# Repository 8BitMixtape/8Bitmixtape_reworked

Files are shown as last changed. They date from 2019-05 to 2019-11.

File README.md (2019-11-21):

# MixtapeNEO reworked
It's not really new... but finally fully working wiht KiCAD and svg2Shenzhen.
Reworked the "classic" 8Bit Mixtape NEO, now with new design, working amplifier 8002 and integrated speaker. Repsoitionend the battery holders, added holes for the speaker and improved the footprints hand-soldering.

## Fully redesigned version

Clone / fork this repo and make your own design!!

### Digilog Version

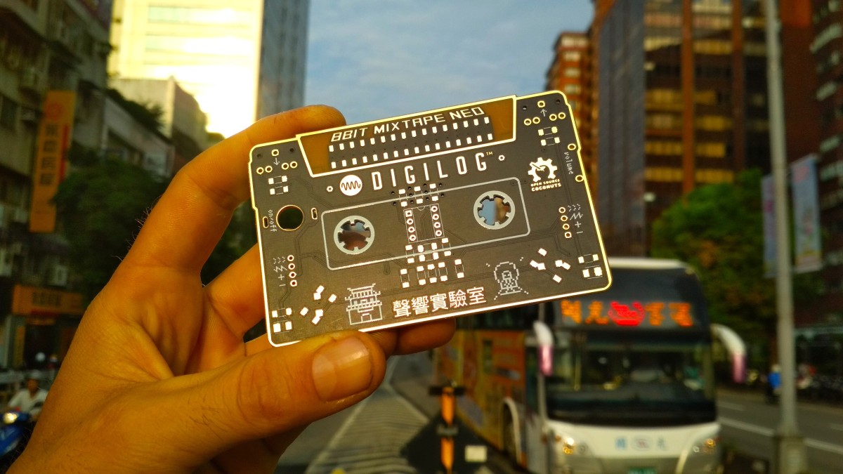
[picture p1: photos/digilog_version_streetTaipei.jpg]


### Pixelache Version

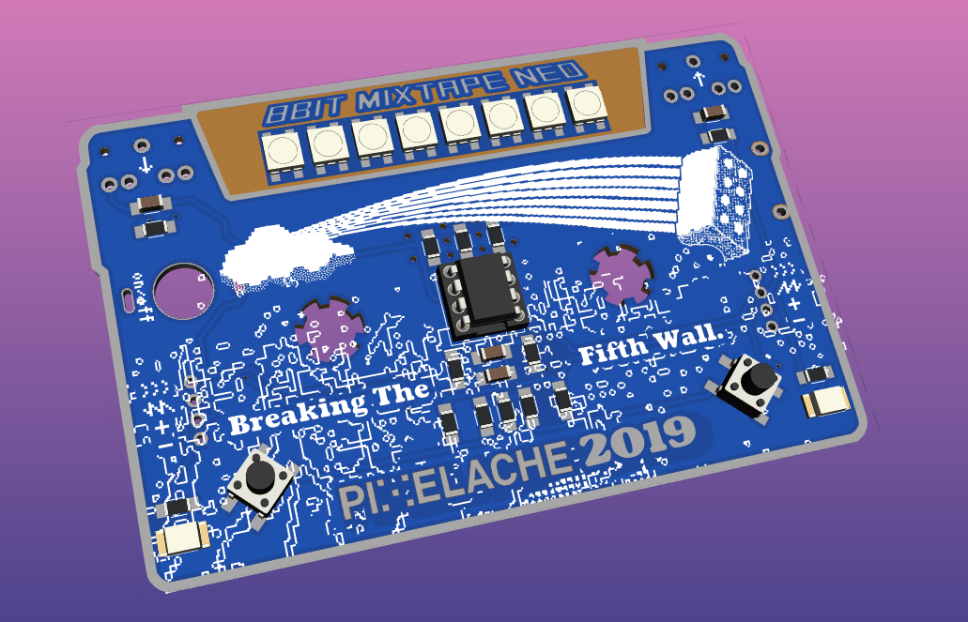
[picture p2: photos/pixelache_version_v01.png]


A limited edition of the Pixelache 2019 Mixtape kits are available from Steve Maher, get in contact with hom on fbook: https://www.facebook.com/steve.maher.39

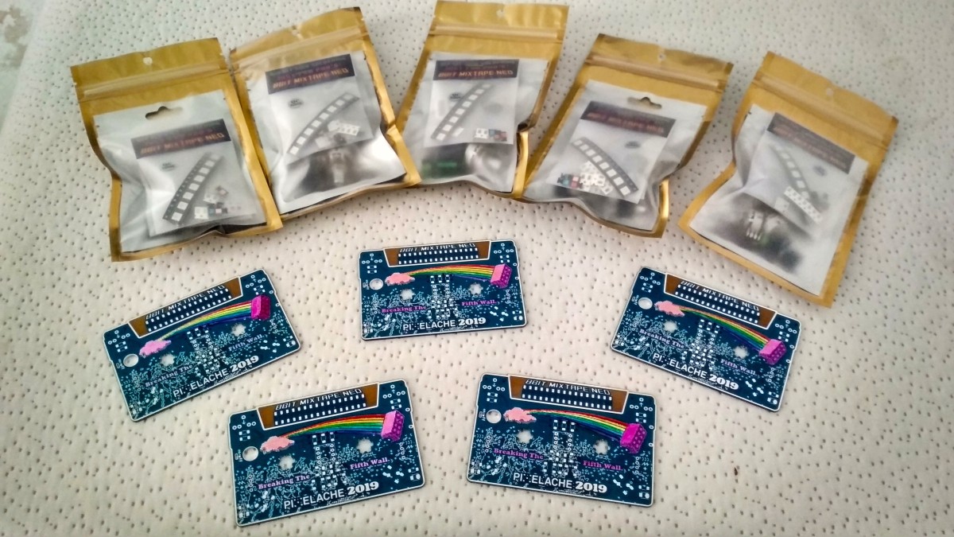
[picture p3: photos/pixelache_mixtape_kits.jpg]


### Make your own Designs!

Modify it in other shapes, such as Eurorack? Make a really really small one? Simplfy it as a little sound toy?

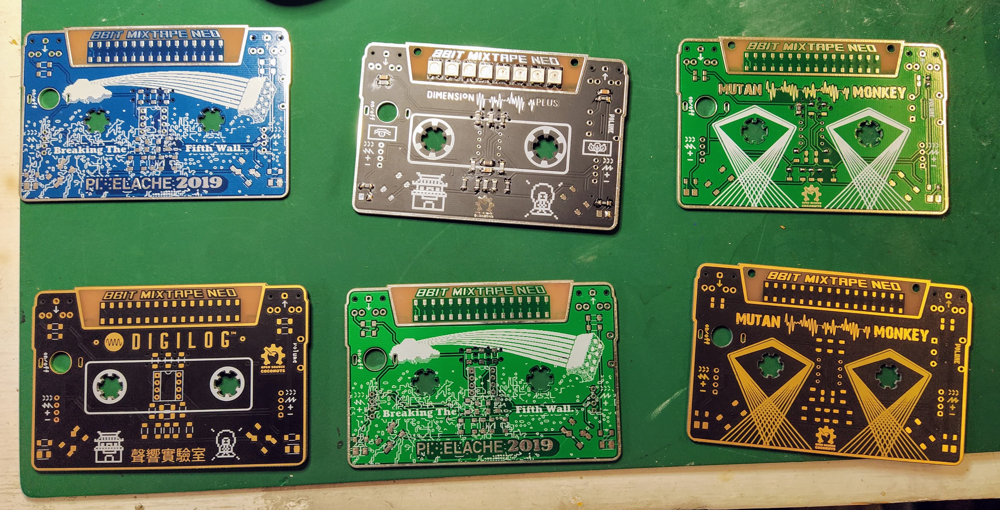
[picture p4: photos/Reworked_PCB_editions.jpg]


### Print your own 3d-case

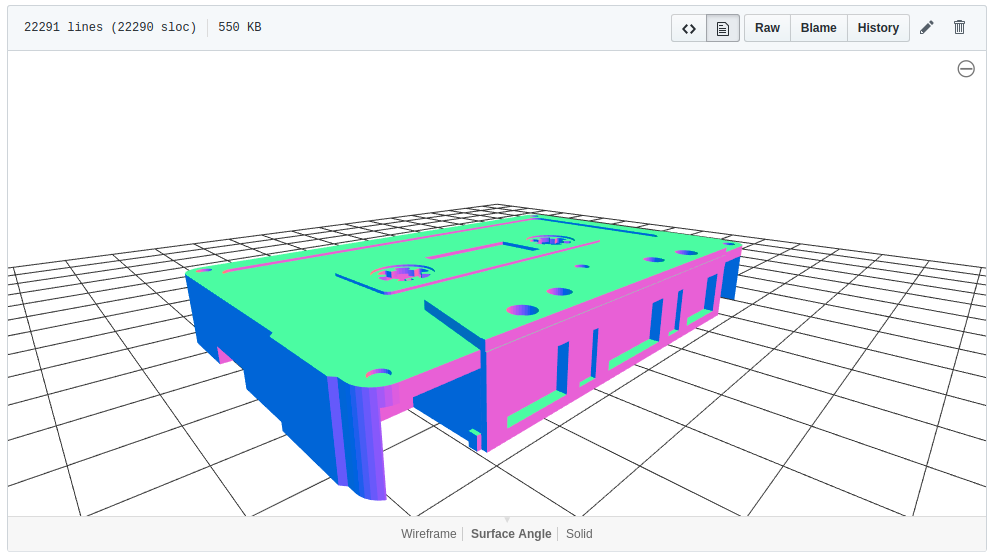
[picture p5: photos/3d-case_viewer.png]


https://github.com/8BitMixtape/8Bitmixtape_reworked/blob/master/3d-case/MixTape_Case_VerMayl19_11.stl

## Soldering Instruction

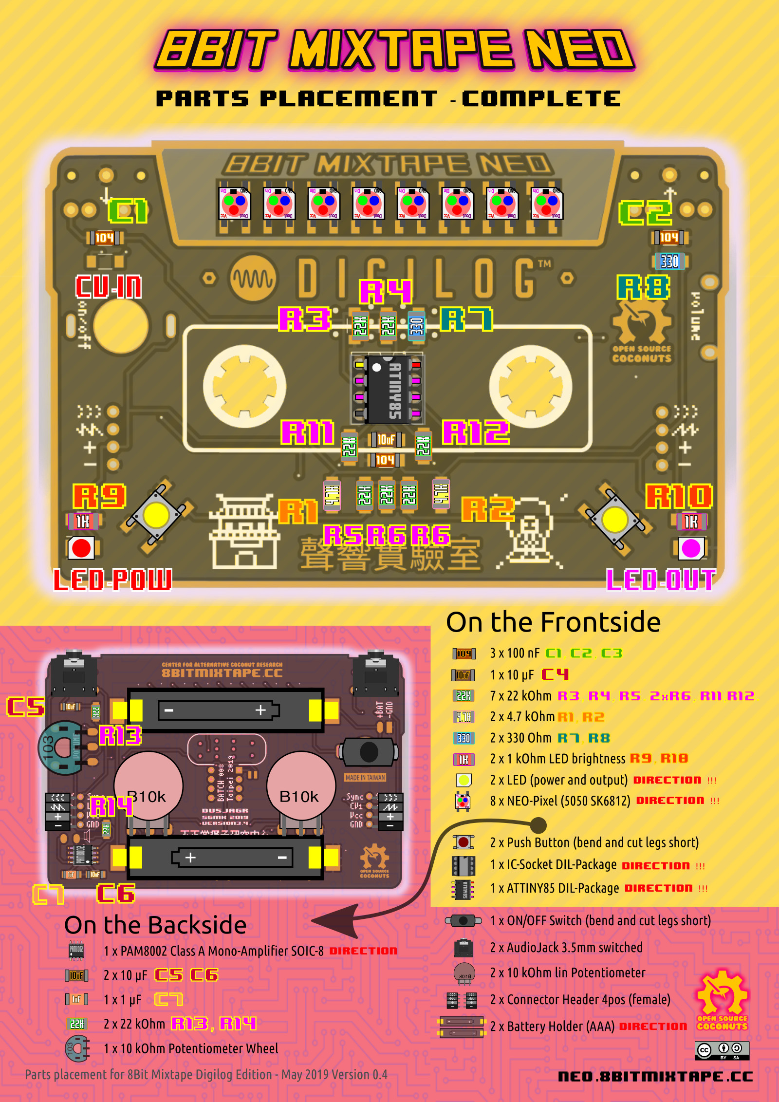
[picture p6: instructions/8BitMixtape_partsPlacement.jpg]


Download printable .pdf here:

https://github.com/8BitMixtape/8Bitmixtape_reworked/blob/master/instructions/Digilog_Mixtape_partsplacement_v04.pdf

## KiCAD PCB and 3d View

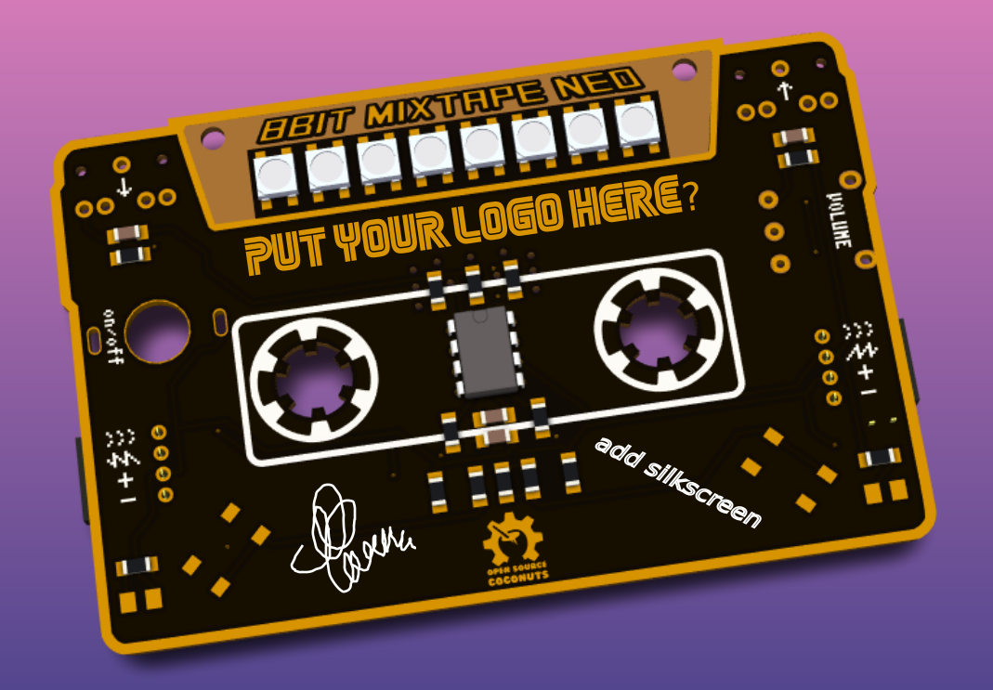
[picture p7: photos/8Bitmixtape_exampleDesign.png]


## KiCAD complete schematic



## KiCAD dedicated footprints

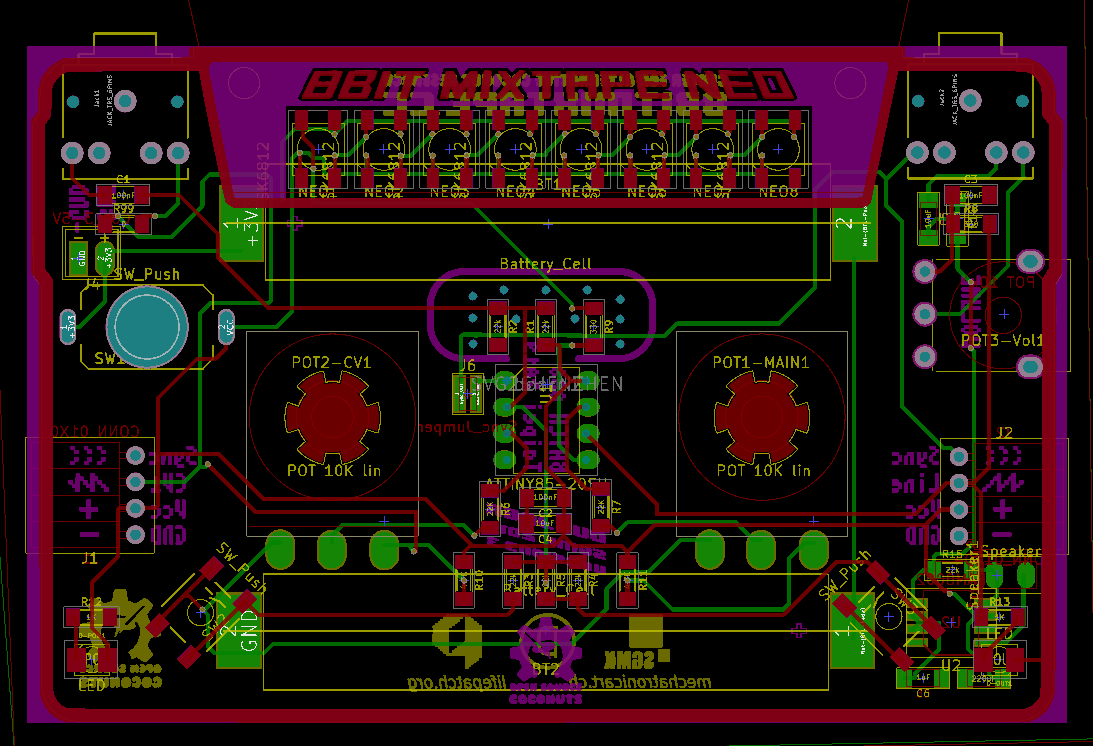
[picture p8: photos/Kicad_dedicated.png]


Optimized footprints and 3d-models DONE. 

### To Add
* LiPo charge management
* (ISP connector)

## creative design layer in Inkscape with svg2shenzhen extension



Empty canvas in inkscape for creating all kind of creative PCB designs, edge.cut and drill layer taken from earlier editions. Use svg2shenzhen extension to export the footpring .kicad_mod to the dedicated footprint library.

See more about svg2shenzhen here: https://github.com/badgeek/svg2shenzhen

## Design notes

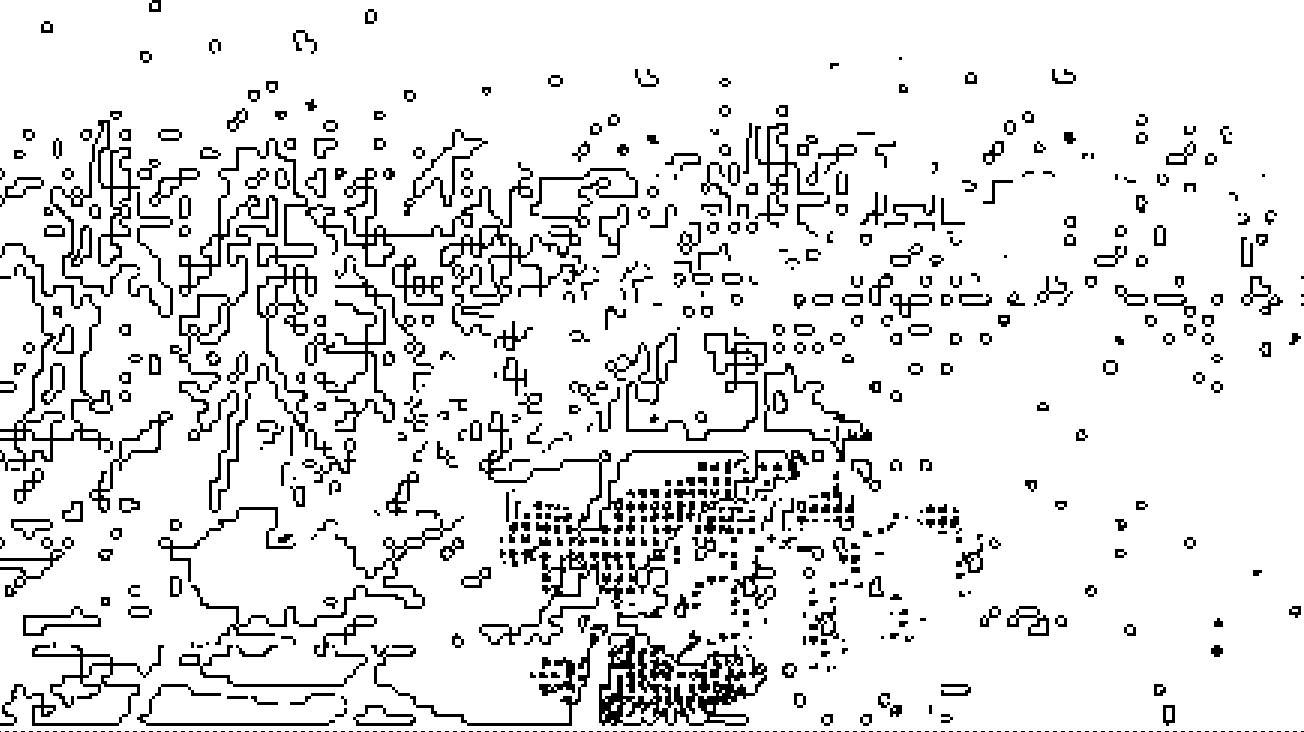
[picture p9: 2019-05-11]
graphics/speckles.png

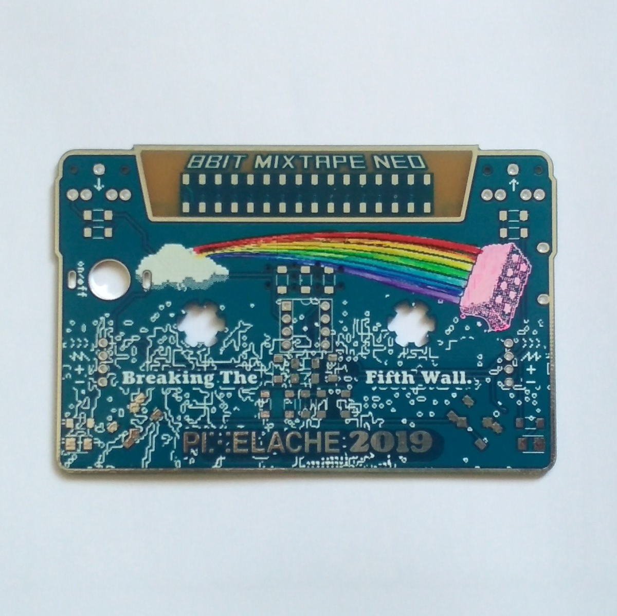
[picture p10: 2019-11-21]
photos/pixelache_mixtape_colored.jpg

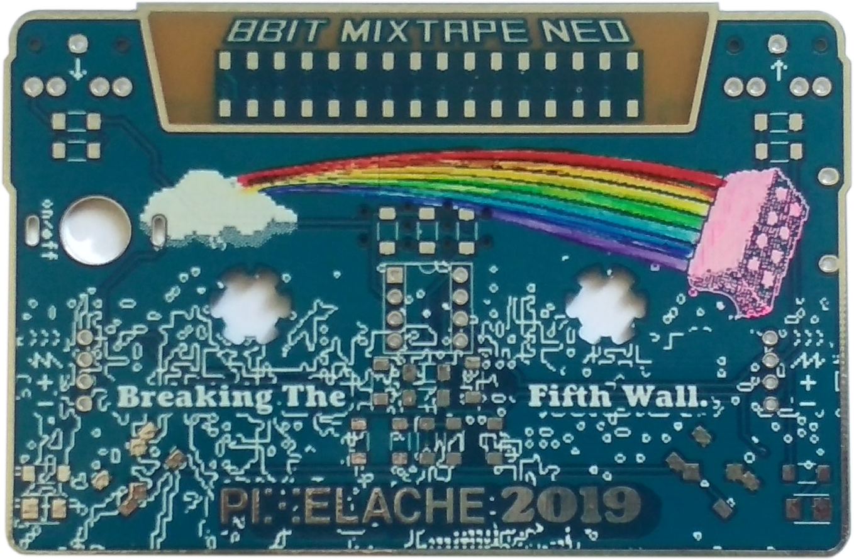
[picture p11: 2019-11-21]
photos/pixelache_mixtape_cropped.png

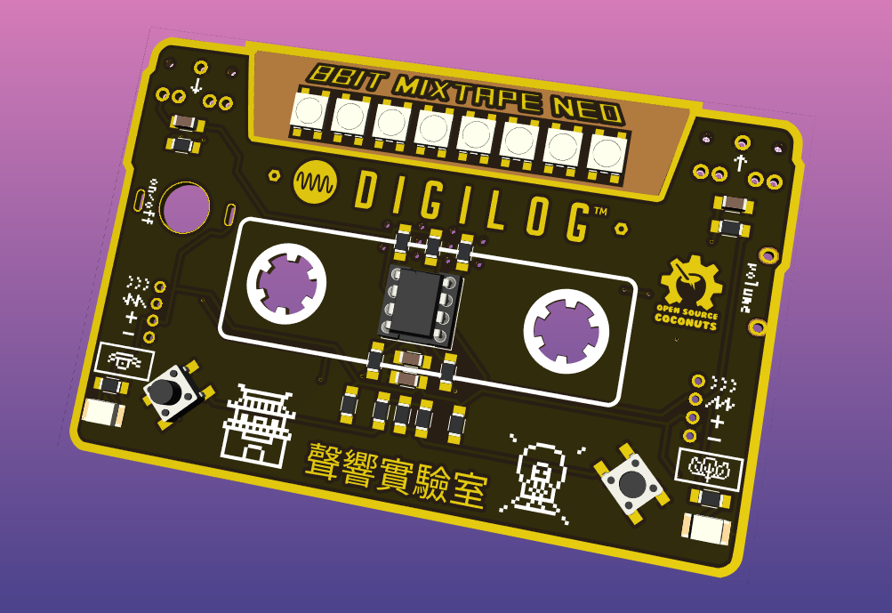
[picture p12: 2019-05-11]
photos/digilog_version_v04.png

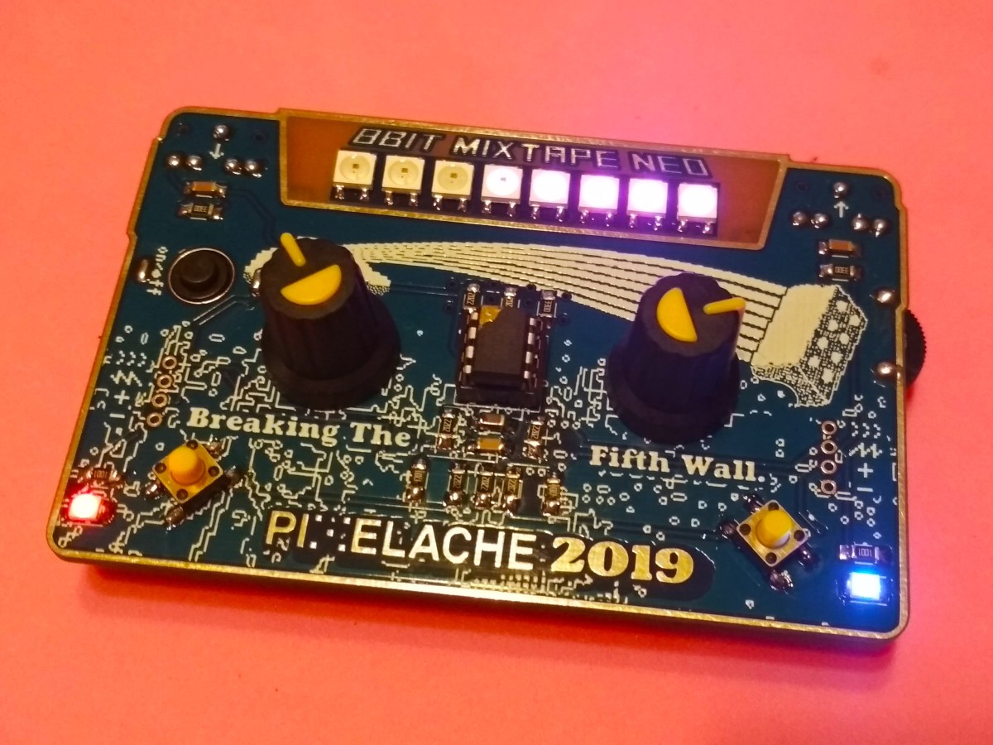
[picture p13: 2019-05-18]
photos/pixelacher_done.jpg

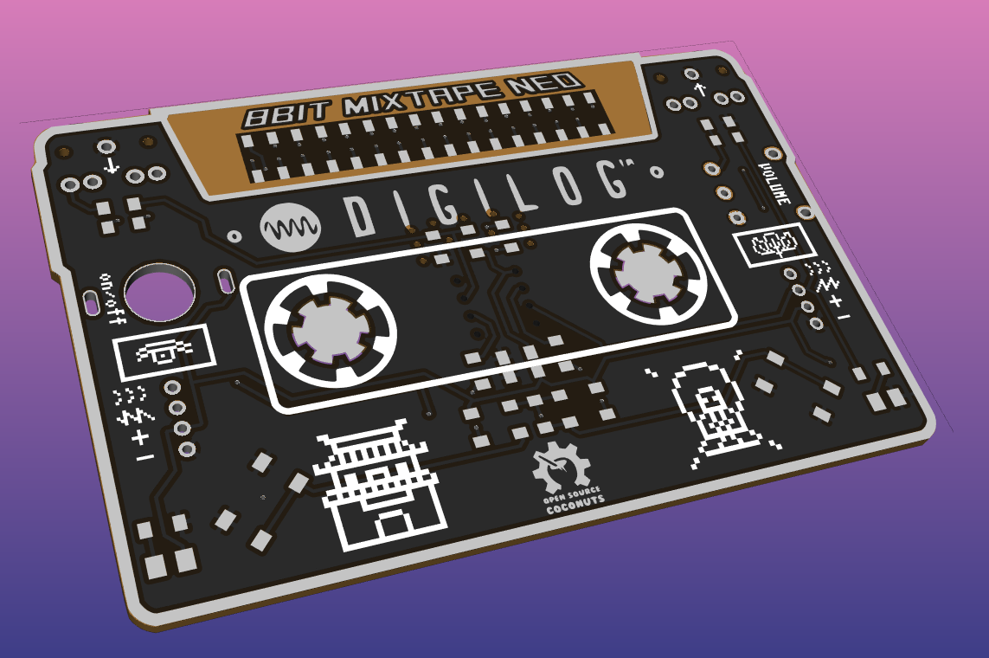
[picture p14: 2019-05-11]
photos/digilog_version.png

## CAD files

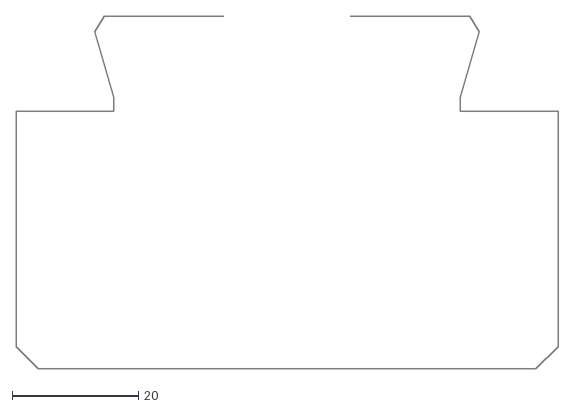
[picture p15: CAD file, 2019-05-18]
3d-case/mixtape_case_3D_MainCase_USB.dxf
86.0 x 56.0

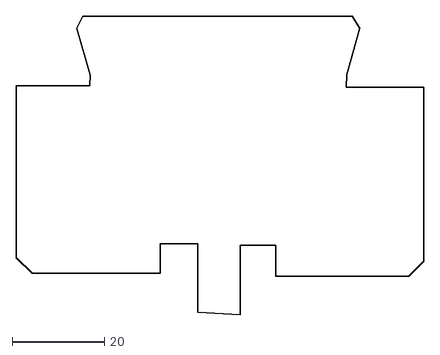
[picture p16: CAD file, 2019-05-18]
3d-case/mixtape_case_3D_MainCase.dxf
88.3 x 64.8

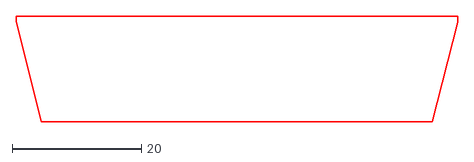
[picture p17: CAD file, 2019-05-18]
3d-case/mixtape_case_3D_TopTrapez.dxf
68.2 x 16.4

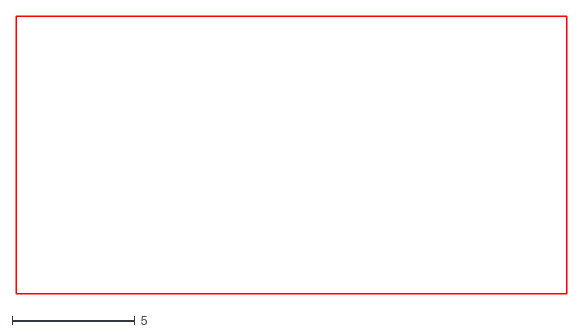
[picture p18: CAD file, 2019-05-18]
3d-case/mixtape_case_3D_WindowRect.dxf
22.4 x 11.3

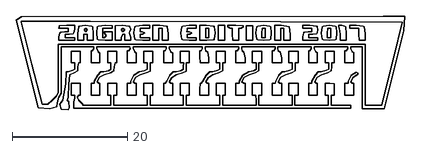
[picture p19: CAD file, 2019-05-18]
3d-case/mixtape_case_3D_PCB_TrapezCircuit.dxf
67.4 x 16.2

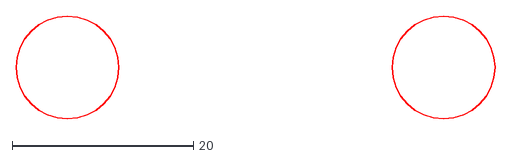
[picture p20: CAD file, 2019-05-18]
3d-case/mixtape_case_3D_Wheels.dxf
52.9 x 11.4

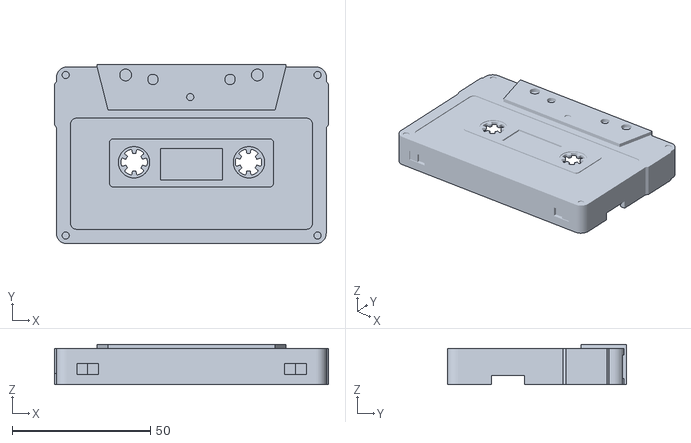
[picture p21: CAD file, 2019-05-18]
3d-case/MixTape_Case_VerMayl19_11.stl
99.0 x 64.8 x 14.6

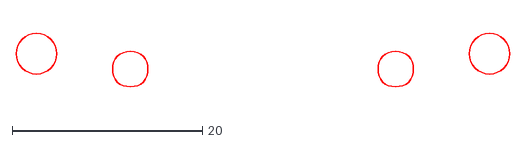
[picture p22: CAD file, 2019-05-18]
3d-case/mixtape_case_3D_Holes.dxf
51.8 x 5.60

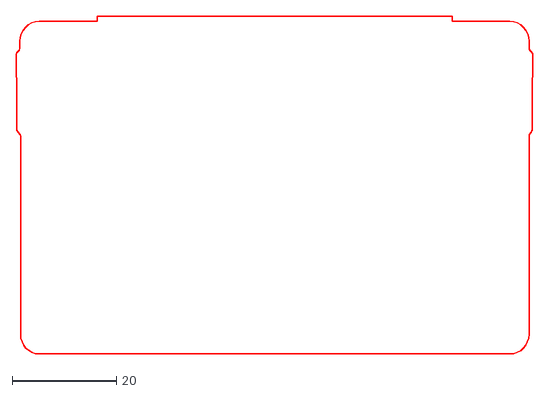
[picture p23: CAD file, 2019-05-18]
3d-case/mixtape_case_3D_bottom.dxf
99.0 x 64.8

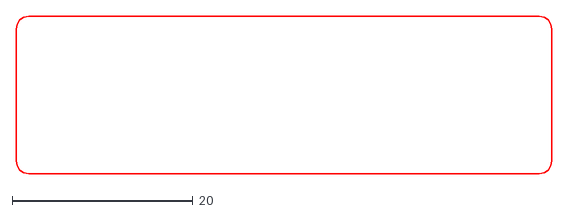
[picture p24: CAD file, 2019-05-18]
3d-case/mixtape_case_3D_MidRect.dxf
59.3 x 17.4

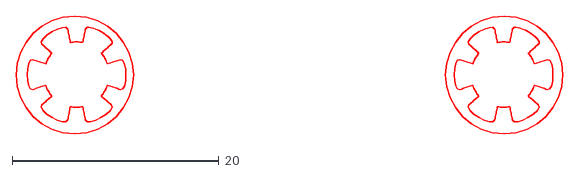
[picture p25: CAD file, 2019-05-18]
3d-case/mixtape_case_3D_NutWheels.dxf
52.9 x 11.4

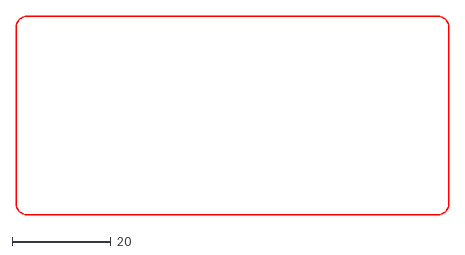
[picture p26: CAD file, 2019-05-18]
3d-case/mixtape_case_3D_BigRect.dxf
87.5 x 40.2

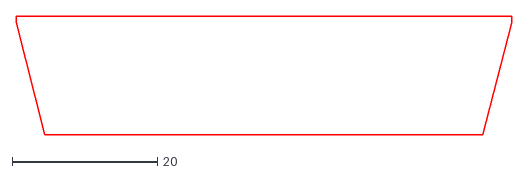
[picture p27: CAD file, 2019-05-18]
3d-case/mixtape_case_3D_PCB_TrapezBoard.dxf
68.2 x 16.4

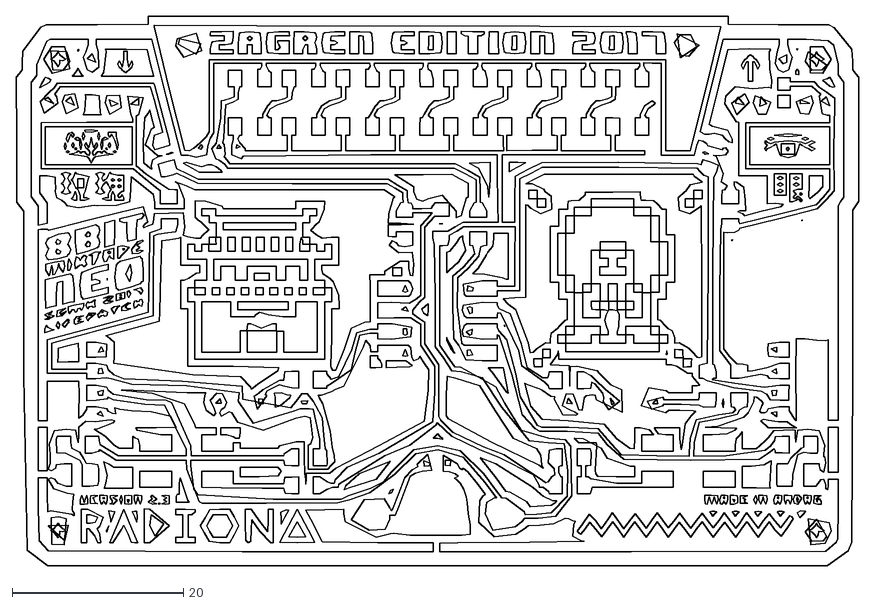
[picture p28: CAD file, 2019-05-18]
3d-case/mixtape_case_3D_PCB.dxf
98.2 x 64.1

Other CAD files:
3d-case/MixTape_Case_VerMayl19_11.scad

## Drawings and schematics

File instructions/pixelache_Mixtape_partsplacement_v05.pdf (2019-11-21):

C1 | C2

R4

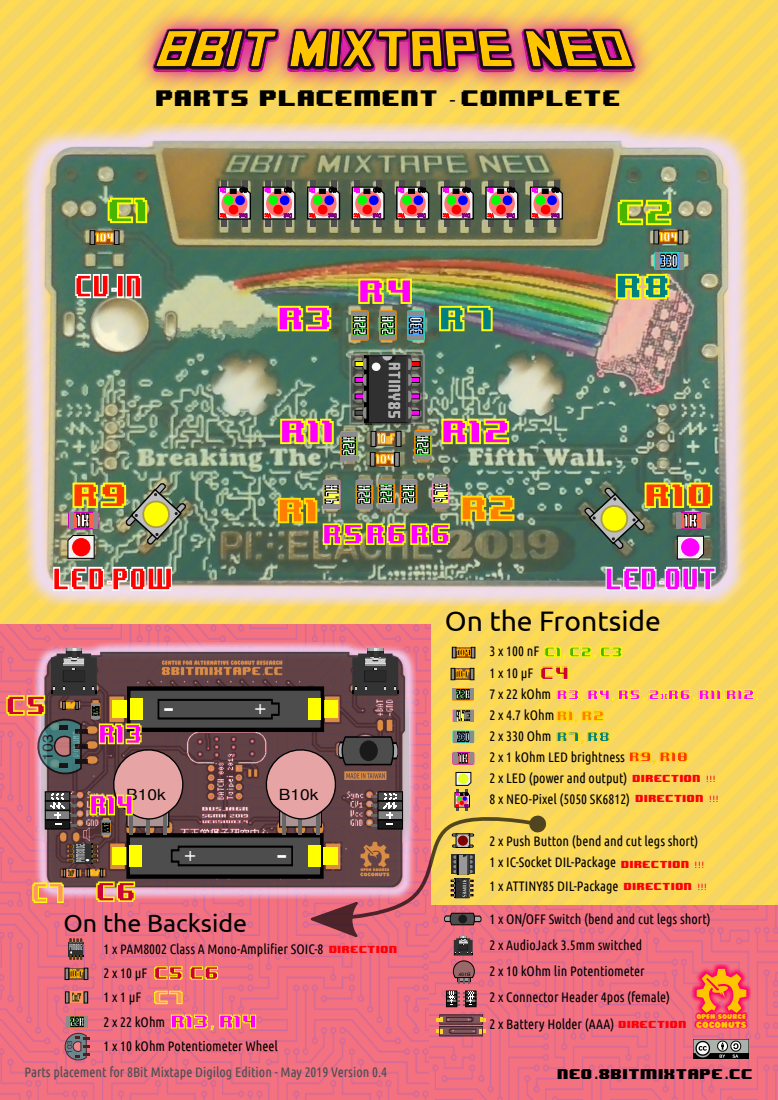
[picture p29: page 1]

2 x LED (power and output) direction !!!

2 x Push Button (bend and cut legs short)
1 x IC-Socket DIL-Package direction !!!
1 x ATTINY85 DIL-Package direction !!!

1 x ON/OFF Switch (bend and cut legs short)
2 x AudioJack 3.5mm switched

1 x PAM8002 Class A Mono-Amplifier SOIC-8
1 x 10 kOhm Potentiometer Wheel

Parts placement for 8Bit Mixtape Digilog Edition - May 2019 Version 0.4

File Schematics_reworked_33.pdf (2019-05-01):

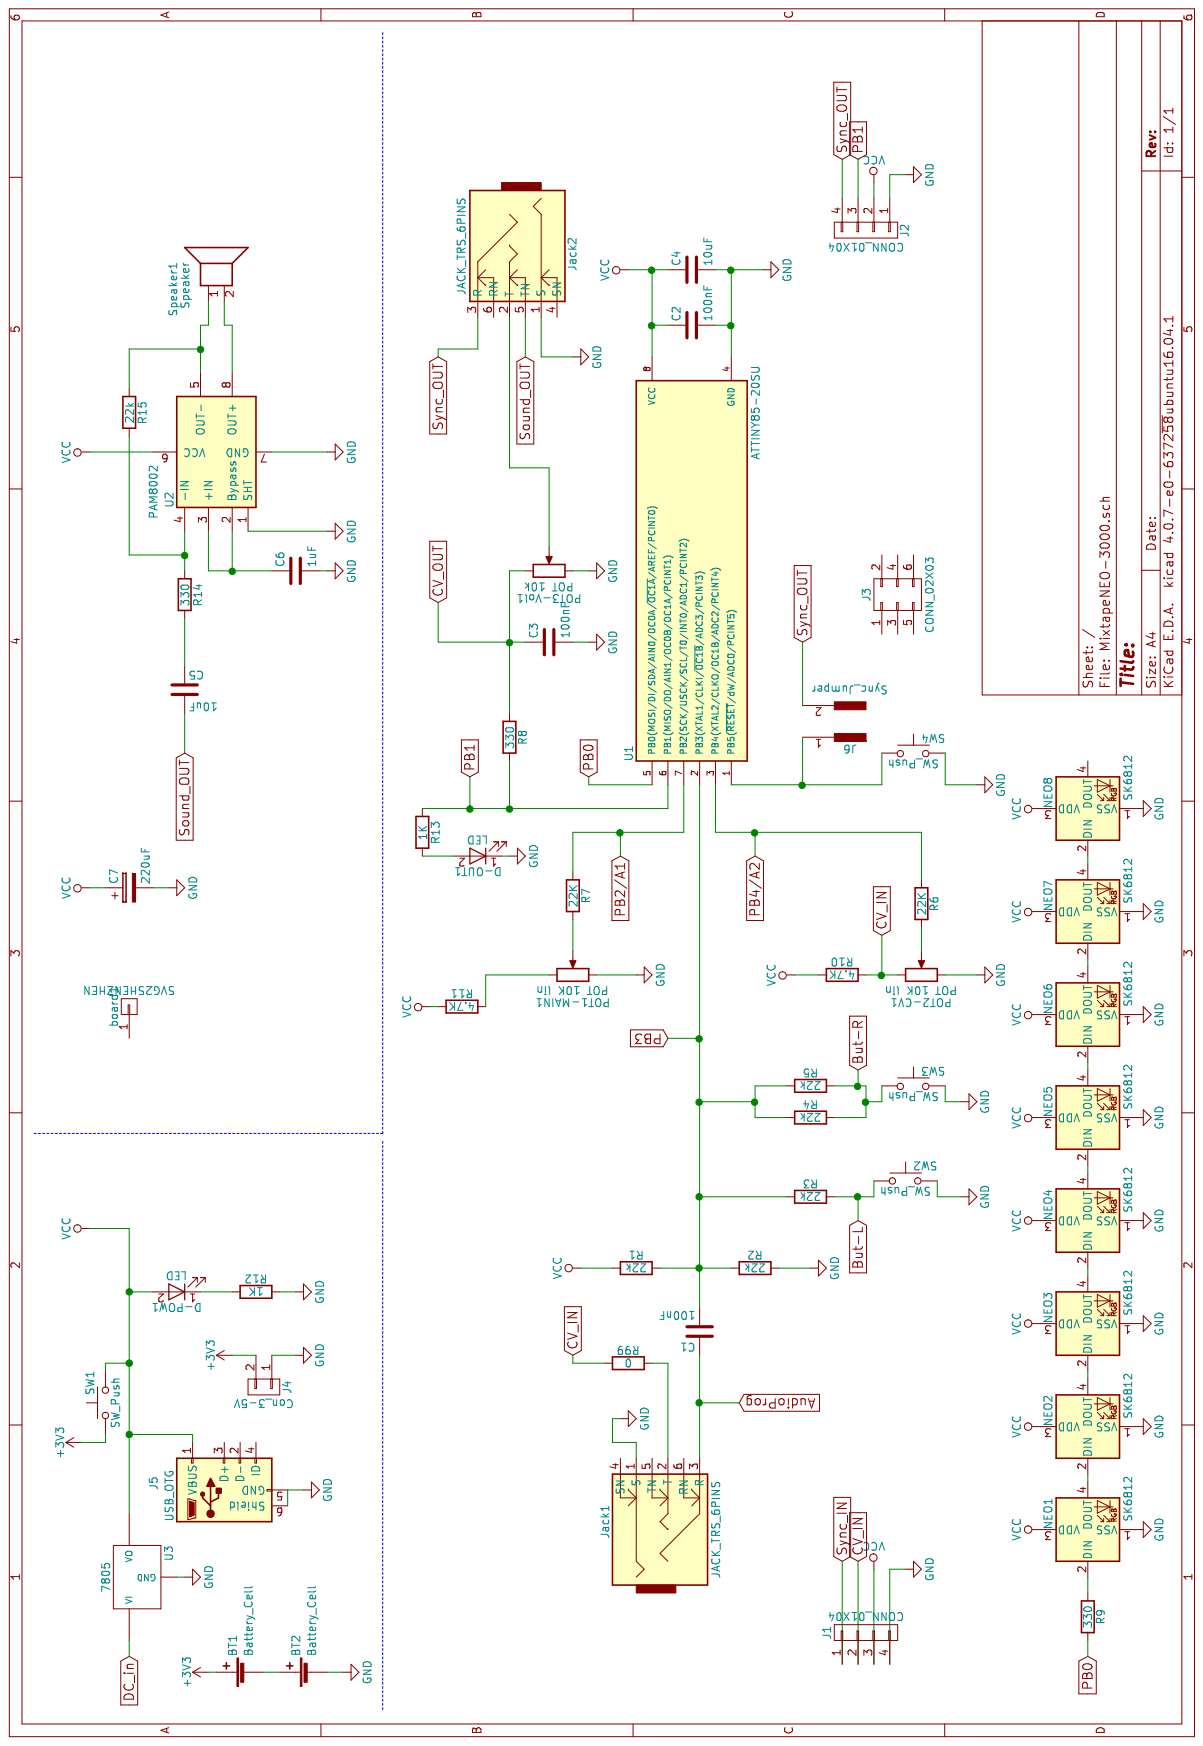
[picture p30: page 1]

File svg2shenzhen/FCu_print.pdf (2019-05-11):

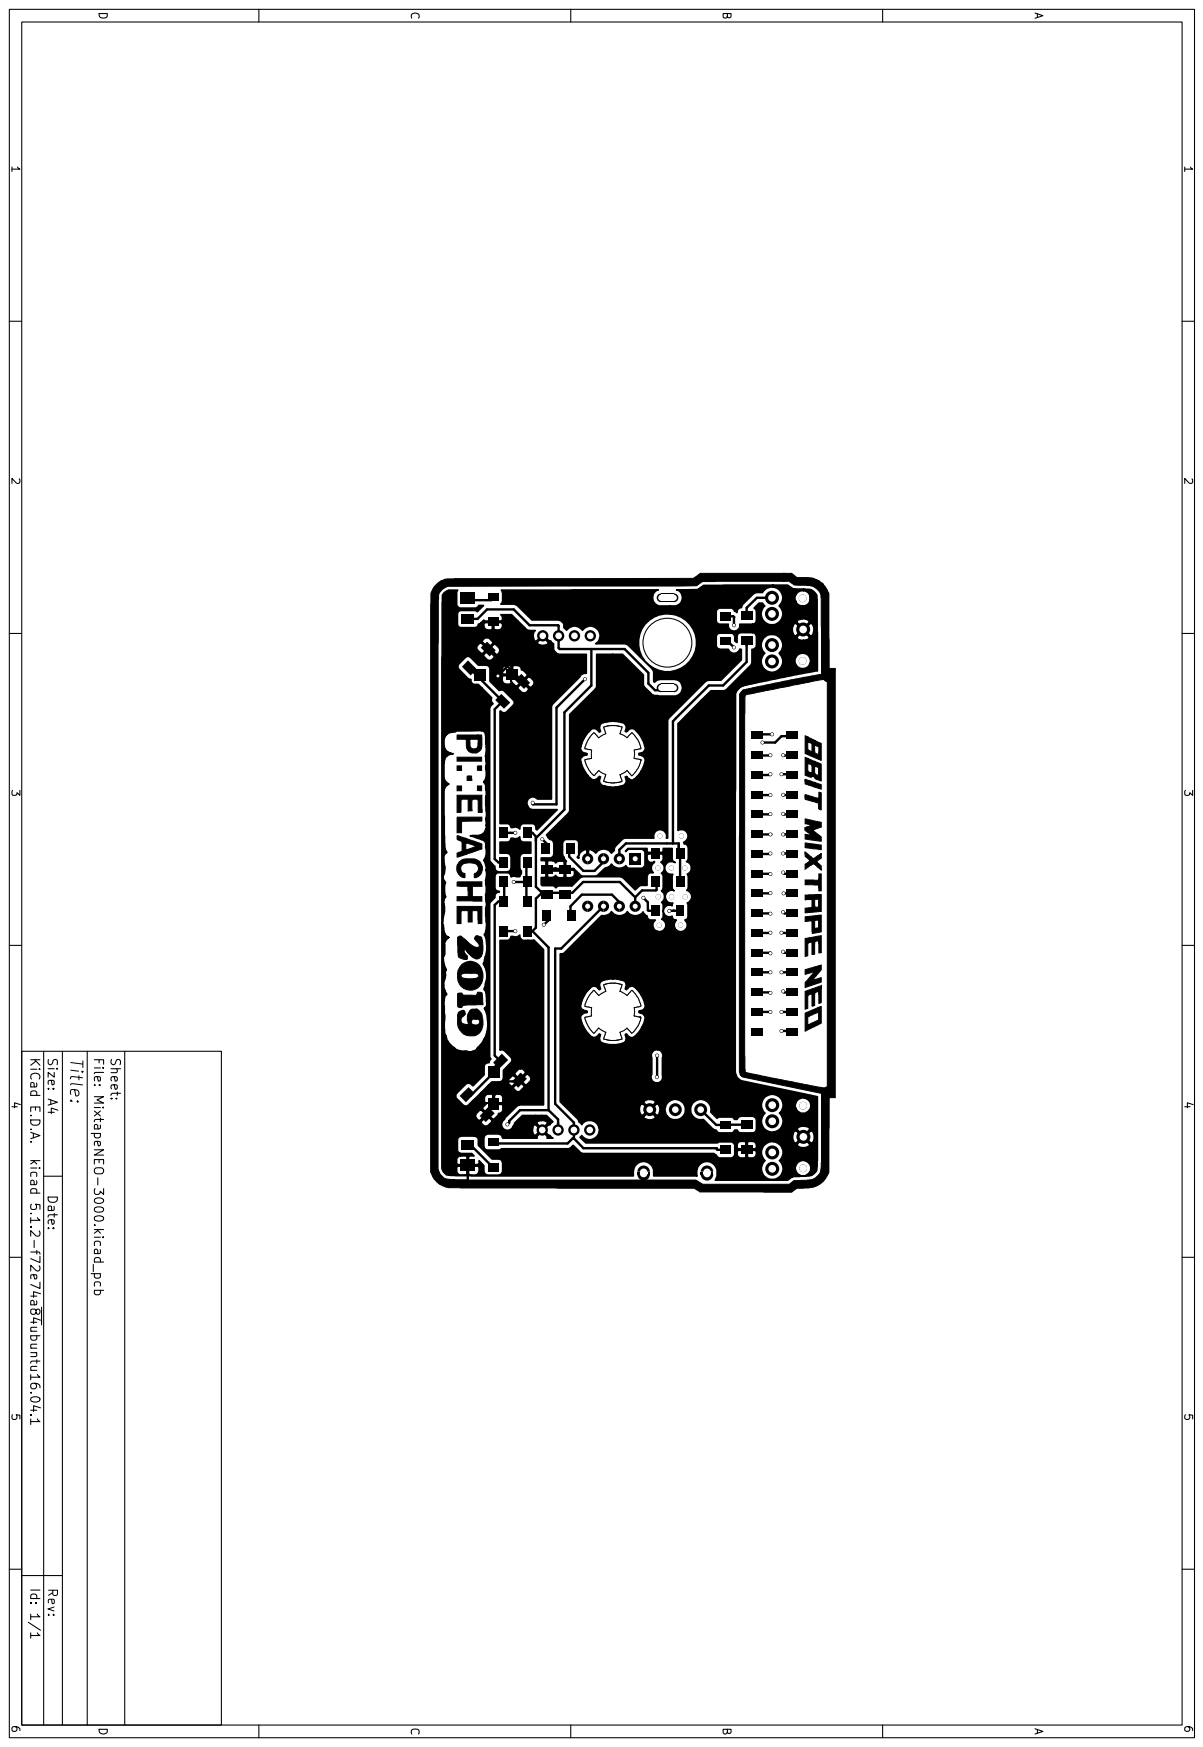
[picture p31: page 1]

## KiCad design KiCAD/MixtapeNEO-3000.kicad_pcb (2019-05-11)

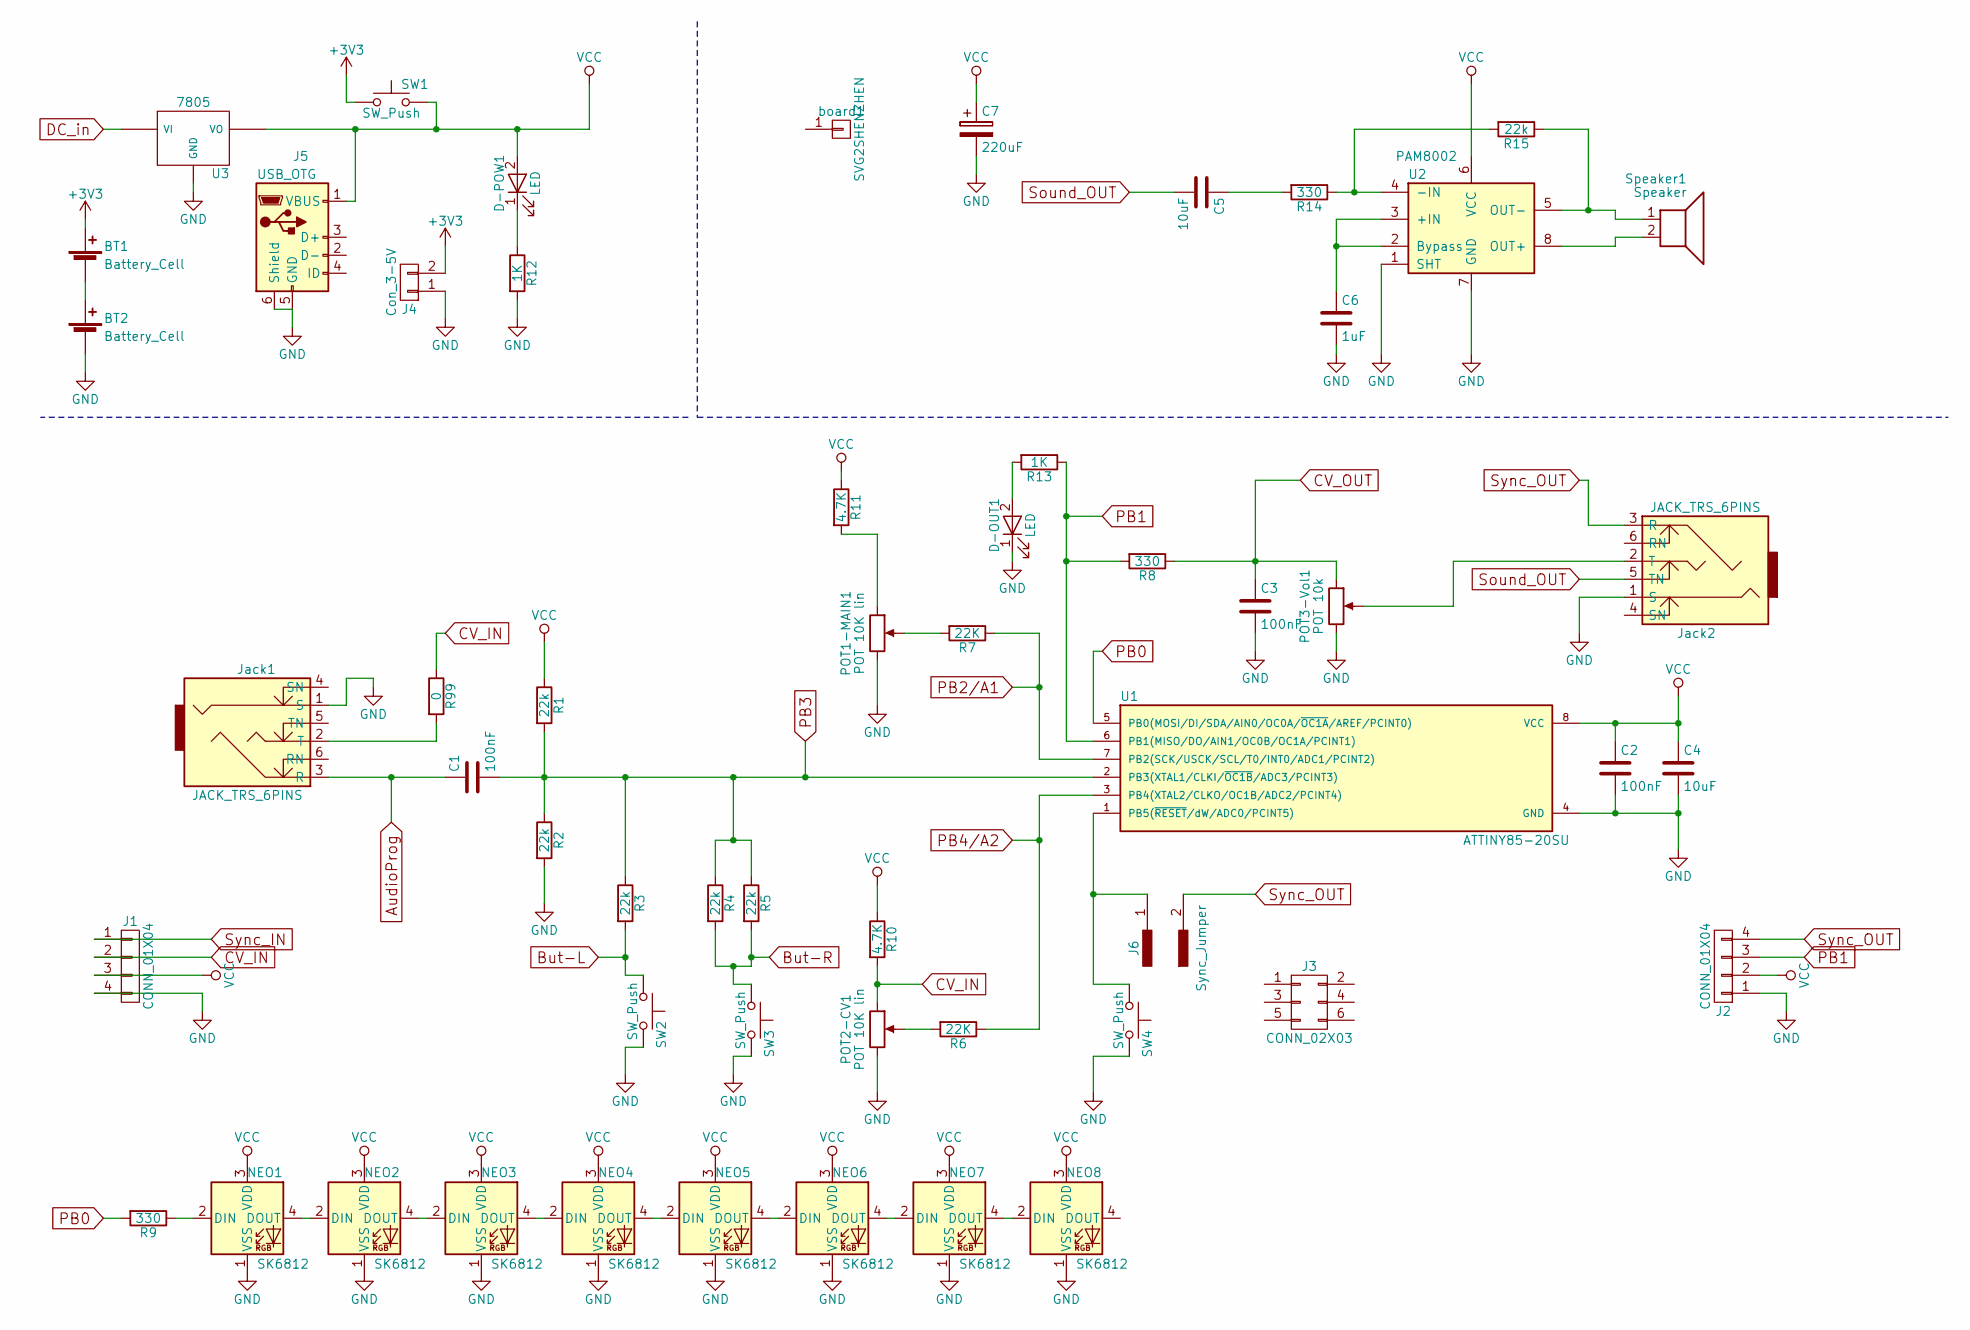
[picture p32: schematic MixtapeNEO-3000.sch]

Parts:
BT1, BT2: Battery_Cell; BAT_Holder_AAA-new_noHole
C1, C2, C3: 100nF; C_1206_HandSoldering
C4, C5: 10uF; C_1206_HandSoldering
C6: 1uF; C_1206_HandSoldering
C7: 220uF; C_1206_HandSoldering
D-OUT1: LED; LED_2835_minimal
D-POW1: LED; LED_2835_minimal
J1, J2: CONN_01X04; Angled_1x04_Pitch2.54mm-flip
J3: CONN_02X03; Socket_Strip_Straight_2x03_Pitch2.54mm
J4: Con_3-5V; Bat_connector_SMD
J5: USB_OTG; USB_Micro-B
J6: Sync_Jumper; Sync_jumper
Jack1, Jack2: JACK_TRS_6PINS; AUDIO-Jack_3.5mm_5Pin
NEO1, NEO2, NEO3, NEO4, NEO5, NEO6, NEO7, NEO8: SK6812; Mixtape_NEO_WS2812B
POT1-MAIN1, POT2-CV1: POT 10K lin; Potentiometer_backPads_noHole
POT3-Vol1: POT 10k; Potentiometer_wheel
R1, R2, R3, R4, R5, R15: 22k; R_1206_HandSoldering
R6, R7: 22K; R_1206_HandSoldering
R8, R9, R14: 330; R_1206_HandSoldering
R10, R11: 4.7K; R_1206_HandSoldering
R12, R13: 1K; R_1206_HandSoldering
R99: 0; R_1206_HandSoldering
SW1: SW_Push; Push_SWITCH_hole
SW2, SW3: SW_Push; TACTILE-PTH_6mm_SMD
SW4: SW_Push; SW_SPST_FSMSM
Speaker1: Speaker; SpeakerPads_SMD
U1: ATTINY85-20SU; Attiny_DIP-8_W7.62mm_mod
U2: PAM8002; SO-8_fixed
U3: 7805; TO-252-3_TabPin2
board1: SVG2SHENZHEN; Mixtape_reworked

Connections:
+3V3: BT1.1 (+), J4.2, SW1.1
AudioProg: C1.1, Jack1.3 (R)
But-L: R3.2, SW2.1
But-R: R4.2, R5.2, SW3.1
CV_IN: J1.2, POT2-CV1.1, R10.2, R99.1
CV_OUT: C3.1, POT3-Vol1.1, R8.1
GND: BT2.2 (-), C2.2, C3.2, C4.2, C6.2, C7.2, D-OUT1.1 (K), J1.4, J2.1, J4.1, J5.5 (GND), J5.6 (Shield), Jack1.1 (S), Jack2.1 (S), NEO1.1 (VSS), NEO2.1 (VSS), NEO3.1 (VSS), NEO4.1 (VSS), NEO5.1 (VSS), NEO6.1 (VSS), NEO7.1 (VSS), NEO8.1 (VSS), POT1-MAIN1.3, POT2-CV1.3, POT3-Vol1.3, R2.2, R12.2, SW2.2, SW3.2, SW4.2, U1.4 (GND), U2.1 (SHT), U2.7 (GND), U3.GND
unnamed: BT1.2 (-), BT2.1 (+)
unnamed: C5.1, R14.2
unnamed: C6.1, U2.2 (Bypass), U2.3 (+IN)
unnamed: D-OUT1.2 (A), R13.2
unnamed: D-POW1.1 (K), R12.1
unnamed: J6.1, SW4.1, U1.1 (PB5(~RESET~/dW/ADC0/PCINT5))
unnamed: Jack1.2 (T), R99.2
unnamed: Jack2.2 (T), POT3-Vol1.2
unnamed: NEO1.2 (DIN), R9.1
unnamed: NEO1.4 (DOUT), NEO2.2 (DIN)
unnamed: NEO2.4 (DOUT), NEO3.2 (DIN)
unnamed: NEO3.4 (DOUT), NEO4.2 (DIN)
unnamed: NEO4.4 (DOUT), NEO5.2 (DIN)
unnamed: NEO5.4 (DOUT), NEO6.2 (DIN)
unnamed: NEO6.4 (DOUT), NEO7.2 (DIN)
unnamed: NEO7.4 (DOUT), NEO8.2 (DIN)
unnamed: POT1-MAIN1.1, R11.2
unnamed: POT1-MAIN1.2, R7.2
unnamed: POT2-CV1.2, R6.2
unnamed: R14.1, R15.2, U2.4 (-IN)
unnamed: R15.1, Speaker1.1, U2.5 (OUT-)
unnamed: Speaker1.2, U2.8 (OUT+)
PB0: R9.2, U1.5 (PB0(MOSI/DI/SDA/AIN0/OC0A/~OC1A~/AREF/P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)
PB1: J2.3, R8.2, R13.1, U1.6 (PB1(MISO/DO/AIN1/OC0B/OC1A/PCINT1))
PB2/A1: R7.1, U1.7 (PB2(SCK/USCK/SCL/T0/INT0/ADC1/PCINT2))
PB3: C1.2, R1.2, R2.1, R3.1, R4.1, R5.1, U1.2 (PB3(XTAL1/CLKI/~OC1B~/ADC3/PCINT3))
PB4/A2: R6.1, U1.3 (PB4(XTAL2/CLKO/OC1B/ADC2/PCINT4))
Sound_OUT: C5.2, Jack2.5 (TN)
Sync_OUT: J2.4, J6.2, Jack2.3 (R)
VCC: C2.1, C4.1, C7.1, D-POW1.2 (A), J1.3, J2.2, J5.1 (VBUS), NEO1.3 (VDD), NEO2.3 (VDD), NEO3.3 (VDD), NEO4.3 (VDD), NEO5.3 (VDD), NEO6.3 (VDD), NEO7.3 (VDD), NEO8.3 (VDD), R1.1, R10.1, R11.1, SW1.2, U1.8 (VCC), U2.6 (VCC), U3.VO

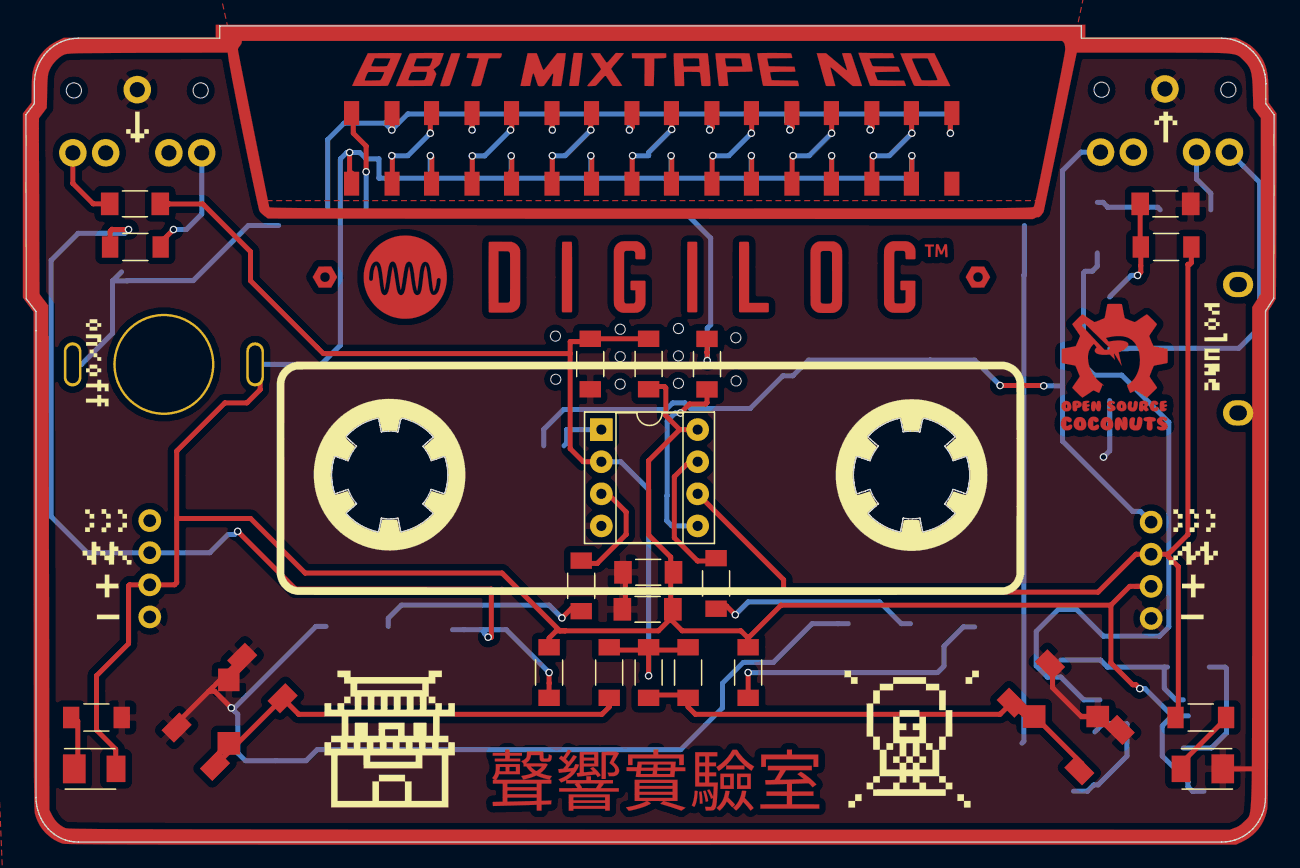
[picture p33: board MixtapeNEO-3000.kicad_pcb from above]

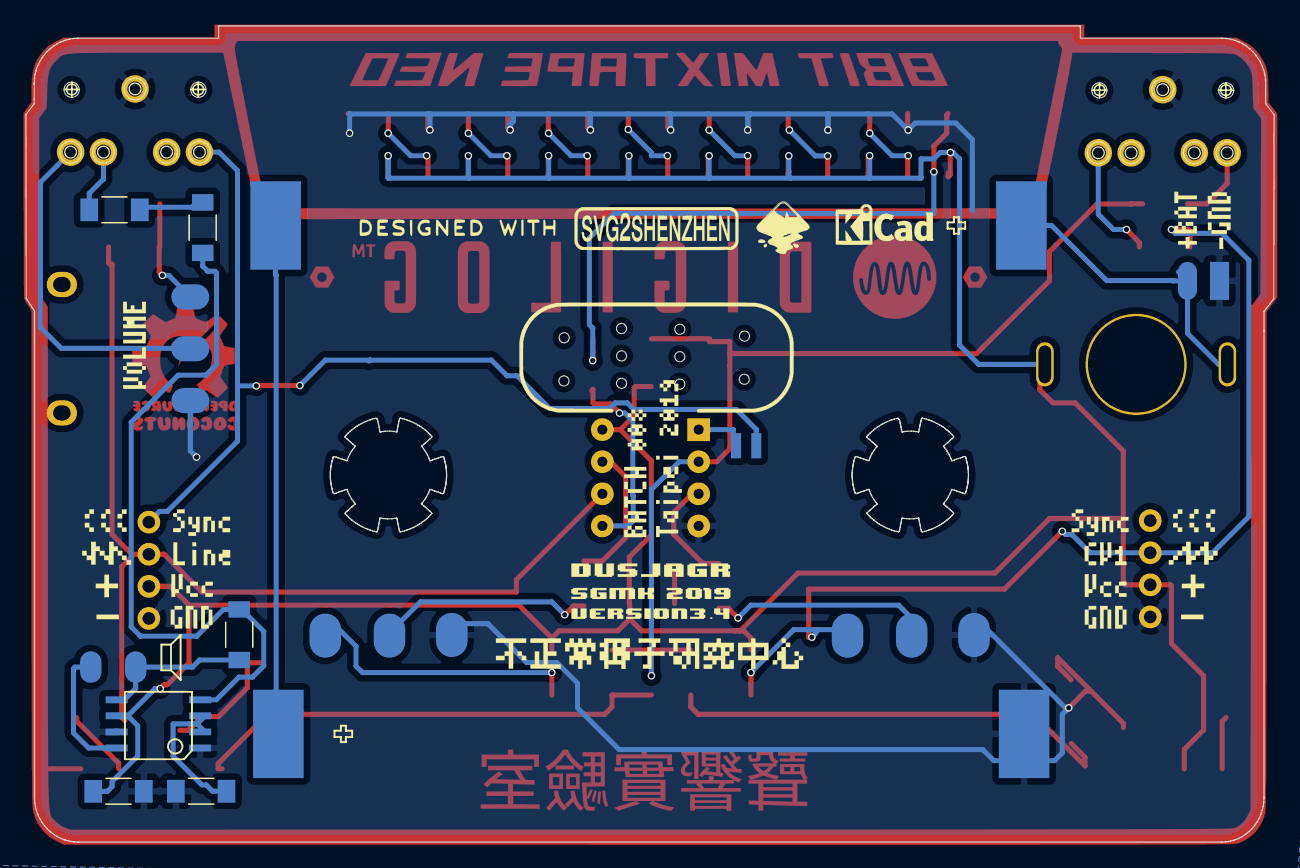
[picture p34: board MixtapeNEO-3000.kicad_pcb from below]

Board: 2 copper layers, 98.8 x 64.6 mm, 55 parts (19 on the bottom side), 37 nets.

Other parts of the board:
Ref**: Val**; dusjagr
Ref**#2: Val**; Coconut_logo_sm
Ref**#3: Val**; CACR_chinese_hori
Ref**#4: Val**; MadeInTaiwan_sm

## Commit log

2019-05-01 adding files
    [MixtapeNEO-3000.kicad_pcb, MixtapeNEO-3000.sch]
2019-05-11 reworked kicad 5 and many new design
    [MixtapeNEO-3000-B_Cu.gbr, MixtapeNEO-3000-B_Mask.gbr, MixtapeNEO-3000-B_SilkS.gbr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]
2019-05-18 moved 3d case here, now with 'click'
    [MixTape_Case_VerMayl19_11.scad, MixTape_Case_VerMayl19_11.stl, mixtape_case_3D_BigRect.dxf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]
2019-11-21 adding photos of all PCBs
    [MixtapeNEO-3000.kicad_pcb]
